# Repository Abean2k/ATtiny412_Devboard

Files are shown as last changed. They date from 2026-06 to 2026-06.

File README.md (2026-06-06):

# ATtiny412_Devboard


Uses an ATtiny 412 or the 212 as the MCU for a very cheap and small dev-board. Developed alongside the USB serial to UDPI Programmer.

## SPECS:
The devboard works with both an ATtiny 412 and an ATtiny 212 in the SOT 8 form-factor. These MCU's have a total of 8 pins. Here are the pinouts for each pin (will be replaced with devboard pinout later):

### ATtiny412 (Recomended Option):
#### Flash: 4 KB
#### SRAM: 256 B
#### EEPROM: 128 B
### ATtiny212: 
#### Flash: 2 KB
#### SRAM: 128 B
#### EEPROM: 64 B

## HOW TO USE:
1. Install or Open Arduino
2. Go to File < Preferences < Additional Boards Manager URLs and paste in "http://drazzy.com/package_drazzy.com_index.json"
3. Go to Tools < Board: and select "ATtiny412/402/212/202"
4. Go to Tools < Clock: and select "20 MHz Internal"
6. Search up and install CH340N Drivers
7. Connect Programmer 3 pins to Devboard 3 pins


8. Flash LED Blink Code
9. It Should Work:)

## PCB:
I made two layer PCBs for each of the two boards. I added ground pours and thicker power traces for hgiher relizablity and more compact size. The devboard user breakouts are breadboard sized and spaced. 
All components are designed to be hand solderable. Note: UPDI pin is not broken out on devboard (SO DNC) to the other user pins as it needs to be kept clear for programming. 

### Devboard Schematic:


### Programmer Schematic:


### Devboard PCB:


### Programmer PCB:


## BOM:
### SerialUPDI Programmer Board
| Component Reference | Description | Package Type | Purpose |
| :--- | :--- | :--- | :--- |
| **U1** | CH340N USB-to-Serial Bridge | SOIC-8 (SOP-8) | Translates computer USB commands into serial data |
| **J2** | USB 2.0 Type-A Male Plug | SMT Edge Mount | Plugs directly into the computer's USB port |
| **R1** | 4.7 kΩ Resistor | SMD (0805) | Junction resistor connecting TXD and RXD for single-wire UPDI |
| **R2** | 1 kΩ Resistor | SMD (0805) | Current-limiting resistor for the Power LED indicator |
| **C1** | 100 nF Ceramic Capacitor | SMD (0805) | Decoupling capacitor for internal V3 regulator (Pin 1) |
| **C2** | 100 nF Ceramic Capacitor | SMD (0805) | Decoupling capacitor for VCC supply line (Pin 7) |
| **D1** | Indicator LED | SMD (0805) | Power-on safety indicator |

### ATtiny412 Student Devboard
| Component Reference | Description | Package Type | Purpose |
| :--- | :--- | :--- | :--- |
| **U1** | ATtiny412 Microcontroller | SOIC-8 (SOP-8) | Main programmable brain (4KB Flash, 256B SRAM) |
| **J1** | 6-Pin USB-C Receptacle | SMT (Single Row Pins) | Supplies power to the board from standard USB cables |
| **R1** | 10 kΩ Resistor | SMD (0805) | UPDI line pull-up|
| **R2** | 1 kΩ Resistor | SMD (0805) | Current-limiting resistor for the user indicator LED |
| **C1** | 100 nF Ceramic Capacitor | SMD (0805) | Main VCC supply line noise decoupling |
| **D1** | User LED | SMD (0805) | Built-in general indicator connected to pin **PA3** (Digital 4) |
| **U2** | AP2112K-3.3 | SOT-23-5 | High-speed 3.3V Linear Regulator for stable chip voltage |
| **Headers**| 2.54mm Breakaway Pins | Through-Hole | Breadboard formate pin breakout rails |

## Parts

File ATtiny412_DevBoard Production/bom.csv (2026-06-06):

Designator | Footprint | Quantity | Value | LCSC Part #
C1, C2 | 0805 | 2 | 1uF
C3 | 0805 | 1 | 100nF
D1 | D_SMA_Handsoldering | 1 | SS14
D2 | 0805 | 1 | LED
J1 | USB_C_Receptacle_HRO_TYPE-C-31-M-17 | 1 | USB_C_Receptacle_PowerOnly_6P
J2 | PinHeader_1x03_P2.54mm_Vertical | 1 | Conn_01x03
J3, J4 | PinHeader_1x04_P2.54mm_Vertical | 2 | Conn_01x04
R1, R2 | 0805 | 2 | 5.1k
R3 | 1206 | 1 | 220R
U1 | SOIC-8_3.9x4.9mm_P1.27mm | 1 | ATtiny412-SS
U2 | SOT-23-5 | 1 | AP2112K-3.3

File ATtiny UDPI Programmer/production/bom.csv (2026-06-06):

Designator | Footprint | Quantity | Value | LCSC Part #
C1, C2 | 0805 | 2 | 100nF
D1 | 0805 | 1 | LED
J1 | PinSocket_1x03_P2.54mm_Vertical | 1 | Conn_01x03
J2 | USB_A_CNCTech_1001-011-01101_Horizontal | 1 | USB_A
R1 | 0805 | 1 | 4.7K
R2 | 0805 | 1 | 1k
U1 | JEITA_SOIC-8_3.9x4.9mm_P1.27mm | 1 | CH340N

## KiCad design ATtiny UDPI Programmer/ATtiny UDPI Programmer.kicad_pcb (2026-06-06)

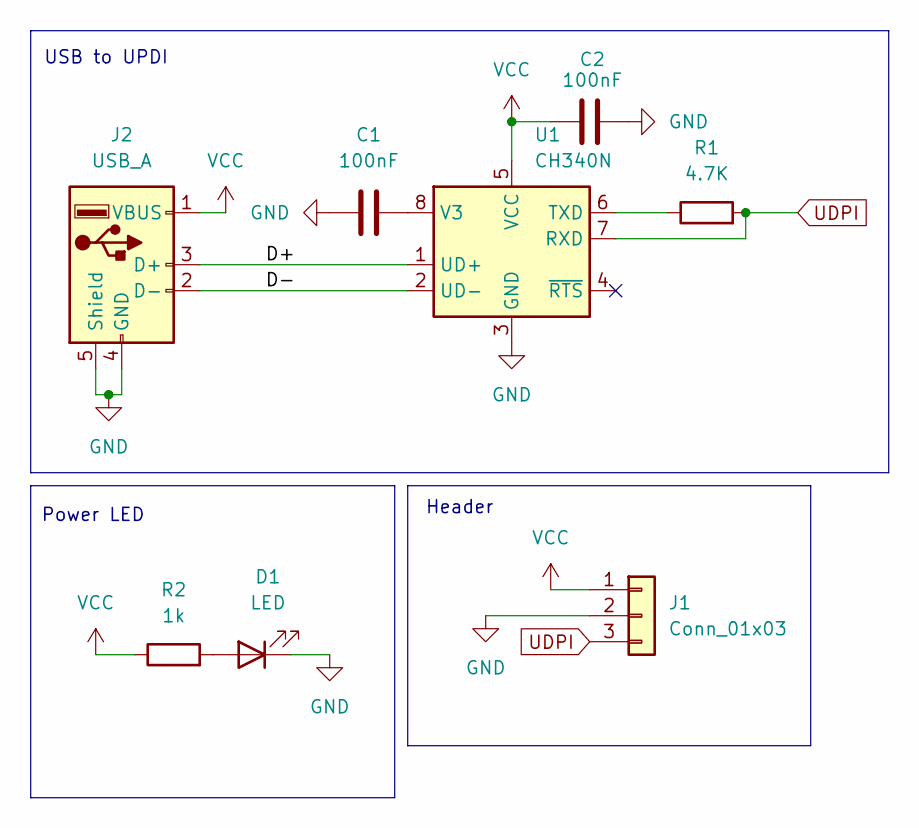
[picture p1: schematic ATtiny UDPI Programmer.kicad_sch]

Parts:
C1, C2: 100nF; C_0805_2012Metric_Pad1.18x1.45mm_HandSolder
D1: LED; LED_0805_2012Metric_Pad1.15x1.40mm_HandSolder
J1: Conn_01x03; PinSocket_1x03_P2.54mm_Vertical
J2: USB_A; USB_A_CNCTech_1001-011-01101_Horizontal
R1: 4.7K; R_0805_2012Metric_Pad1.20x1.40mm_HandSolder
R2: 1k; R_0805_2012Metric_Pad1.20x1.40mm_HandSolder
U1: CH340N; JEITA_SOIC-8_3.9x4.9mm_P1.27mm

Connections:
/D+: J2.3 (D+), U1.1 (UD+)
/D-: J2.2 (D-), U1.2 (UD-)
GND: C1.2, C2.2, D1.1 (K), J1.2, J2.4 (GND), J2.5 (Shield), U1.3 (GND)
unnamed: D1.2 (A), R2.2
unnamed: R1.1, U1.6 (TXD)
unnamed: C1.1, U1.8 (V3)
UDPI: J1.3, R1.2, U1.7 (RXD)
VCC: C2.1, J1.1, J2.1 (VBUS), R2.1, U1.5 (VCC)

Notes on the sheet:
Header
USB to UPDI
Power LED

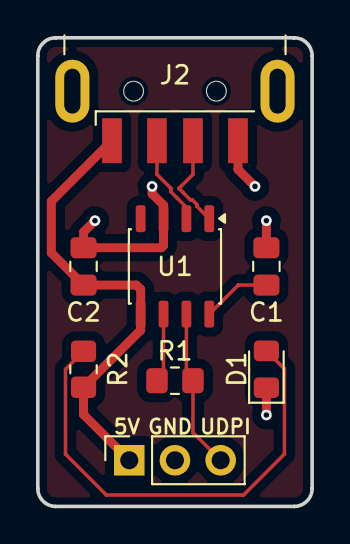
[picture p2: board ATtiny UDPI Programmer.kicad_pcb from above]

Board: 2 copper layers, 15.2 x 26.0 mm, 8 parts (0 on the bottom side), 8 nets.

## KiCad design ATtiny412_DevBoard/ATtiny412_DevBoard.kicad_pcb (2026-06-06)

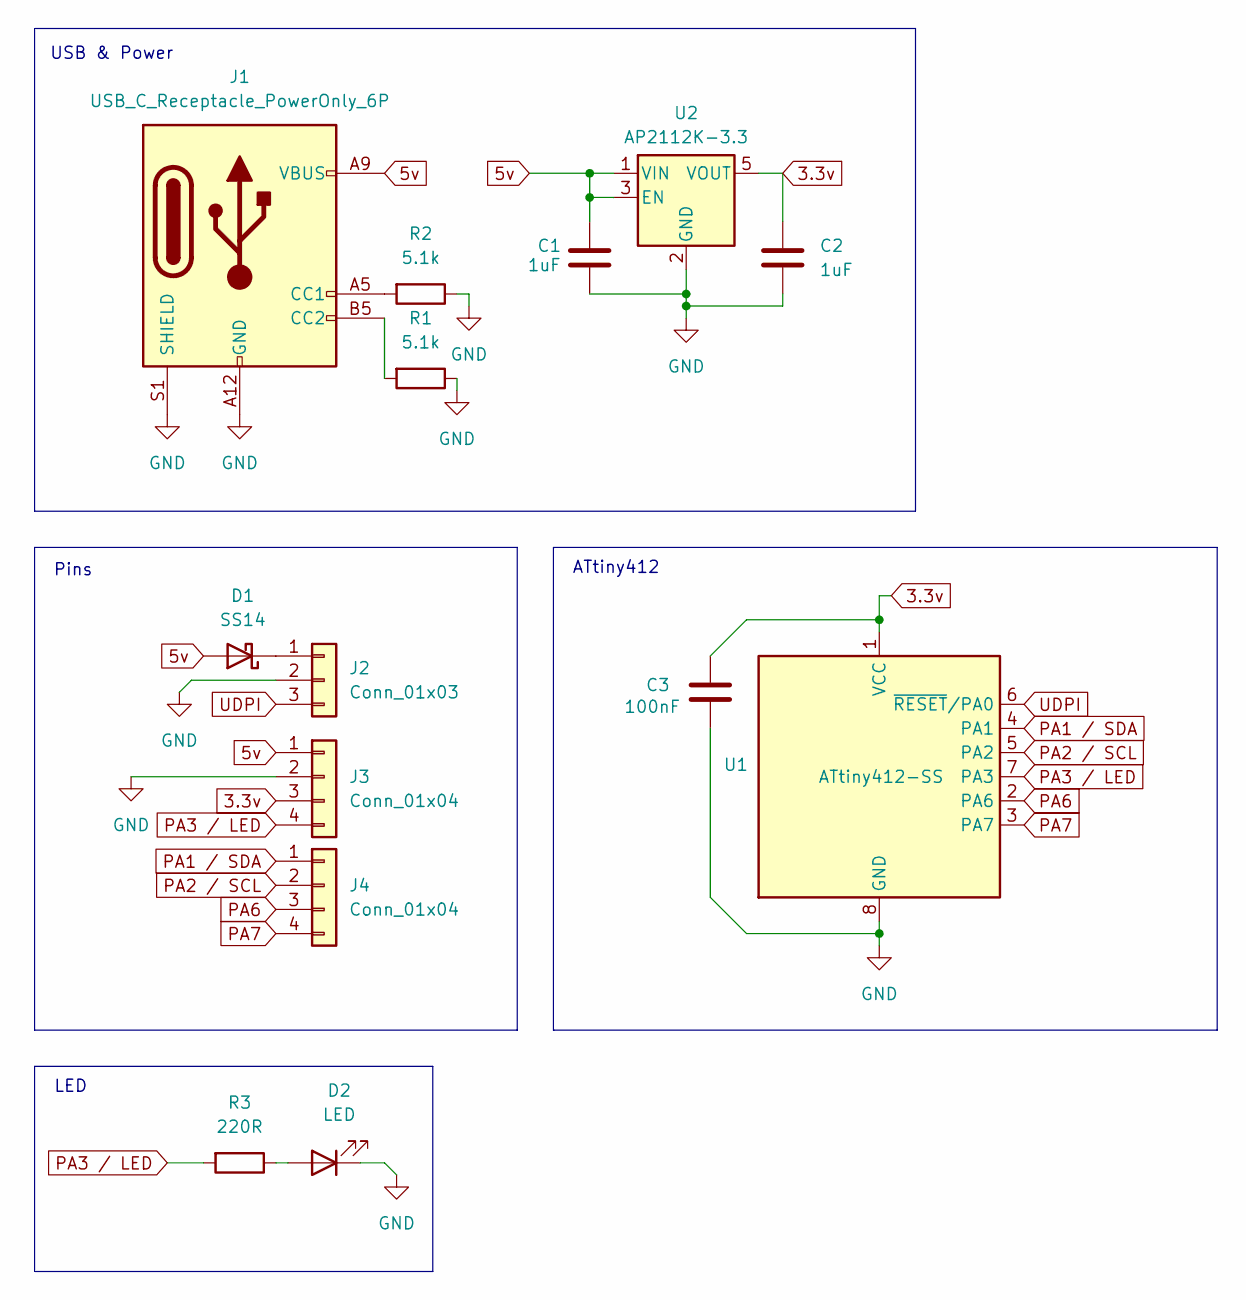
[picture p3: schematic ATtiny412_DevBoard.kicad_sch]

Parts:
C1, C2: 1uF; C_0805_2012Metric_Pad1.18x1.45mm_HandSolder
C3: 100nF; C_0805_2012Metric_Pad1.18x1.45mm_HandSolder
D1: SS14; D_SMA_Handsoldering
D2: LED; LED_0805_2012Metric_Pad1.15x1.40mm_HandSolder
J1: USB_C_Receptacle_PowerOnly_6P; USB_C_Receptacle_HRO_TYPE-C-31-M-17
J2: Conn_01x03; PinHeader_1x03_P2.54mm_Vertical
J3, J4: Conn_01x04; PinHeader_1x04_P2.54mm_Vertical
R1, R2: 5.1k; R_0805_2012Metric_Pad1.20x1.40mm_HandSolder
R3: 220R; R_1206_3216Metric_Pad1.30x1.75mm_HandSolder
U1: ATtiny412-SS; SOIC-8_3.9x4.9mm_P1.27mm
U2: AP2112K-3.3; SOT-23-5

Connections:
3.3v: C2.1, C3.1, J3.3, U1.1 (VCC), U2.5 (VOUT)
5v: C1.1, D1.2 (A), J1.A9 (VBUS), J1.B9 (VBUS), J3.1, U2.1 (VIN), U2.3 (EN)
GND: C1.2, C2.2, C3.2, D2.1 (K), J1.A12 (GND), J1.B12 (GND), J1.S1 (SHIELD), J2.2, J3.2, R1.1, R2.1, U1.8 (GND), U2.2 (GND)
unnamed: D1.1 (K), J2.1
unnamed: D2.2 (A), R3.1
unnamed: J1.A5 (CC1), R2.2
unnamed: J1.B5 (CC2), R1.2
PA1 / SDA: J4.1, U1.4 (PA1)
PA2 / SCL: J4.2, U1.5 (PA2)
PA3 / LED: J3.4, R3.2, U1.7 (PA3)
PA6: J4.3, U1.2 (PA6)
PA7: J4.4, U1.3 (PA7)
UDPI: J2.3, U1.6 (~RESET/PA0)

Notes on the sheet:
LED
USB & Power
ATtiny412
Pins

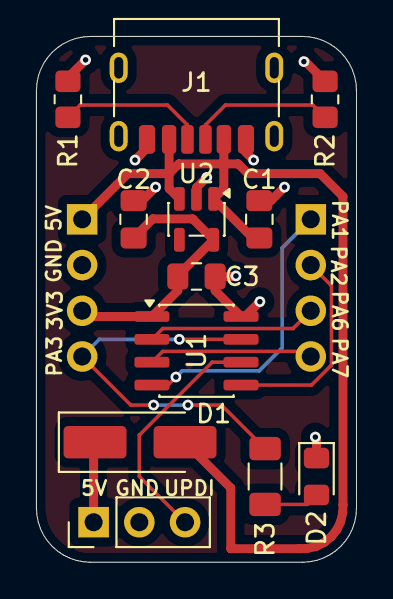
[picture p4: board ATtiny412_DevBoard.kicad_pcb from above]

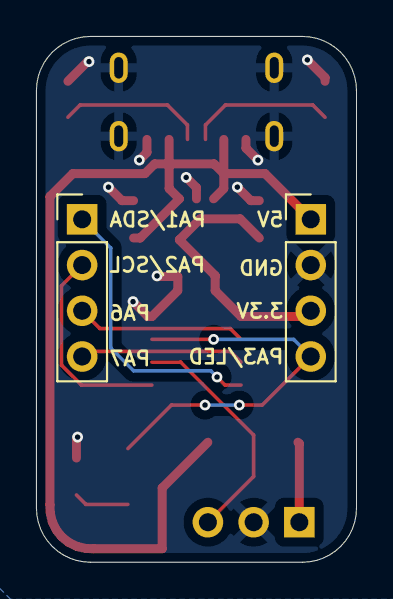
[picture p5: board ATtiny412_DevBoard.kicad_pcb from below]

Board: 2 copper layers, 17.8 x 29.2 mm, 14 parts (2 on the bottom side), 13 nets.

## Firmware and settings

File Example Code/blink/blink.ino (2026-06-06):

//Very simple blink sketch using onboard led, tol test devboard and UDPI pogrammer board. 

// PA3 on ATtiny412 is Aurdiuno Digital Pin 4 
const int LEDPIN = 4;

void setup() {
  // put your setup code here, to run once:
     pinMode(LEDPIN, OUTPUT);
}

void loop() {
  // put your main code here, to run repeatedly:
    digitalWrite(LEDpin, HIGH); // Turn LED ON
    delay(1000); // Wait for 1 second
    digitalWrite(LEDpin, LOW); // Turn LED OFF
    delay(1000); // Wait for 1 second
}

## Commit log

2026-06-06 All PCB and Kicad Files
    [ATtiny UDPI Programmer.kicad_pcb, ATtiny UDPI Programmer.kicad_sch, ATtiny412_DevBoard.kicad_pcb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]
2026-06-06 Update README with UPDI pin information
2026-06-06 Fix heading formatting for BOM section in README
2026-06-06 organized files
    [bom.csv, designators.csv, positions.csv]
2026-06-06 Add BOM sections for Programmer PCB and ATtiny412 board
2026-06-06 Edited BOM
